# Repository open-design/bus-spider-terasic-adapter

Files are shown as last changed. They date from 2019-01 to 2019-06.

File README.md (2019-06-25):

UEXT adapter board for Terasic FPGA development boards with 40-pin expansion headers.

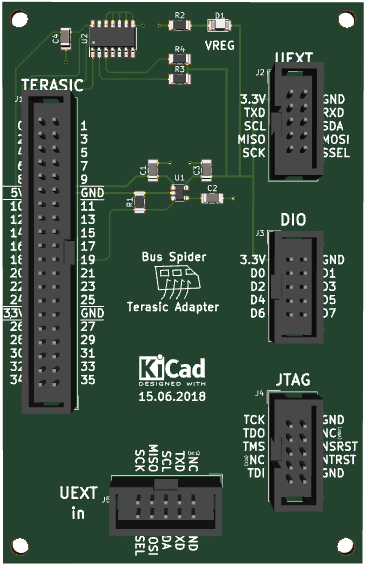
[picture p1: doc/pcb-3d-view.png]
PCB 3D view


## Schematic

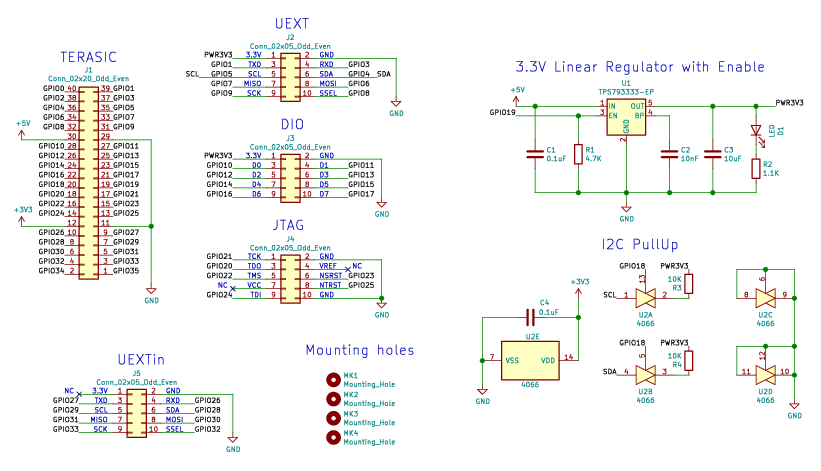
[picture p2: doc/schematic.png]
schematic


## BOM

| name | designation | designator | quantity | supply | datasheets |
| ---  | --- | --- | --- | --- | --- |
| CONNFLY BH-10 | Conn_02x05_Odd_Even | J5,J2,J3,J4 | 4 |  [electronshik.ru](https://www.electronshik.ru/item/CONNFLY/BH-10)<br /> | [pdf](https://static.chipdip.ru/lib/463/DOC002463525.pdf) |
| CONNFLY BH-40 | Conn_02x20_Odd_Even | J1 | 1 |  [electronshik.ru](https://www.electronshik.ru/item/CONNFLY/BH-40)<br /> | [pdf](https://static.chipdip.ru/lib/463/DOC002463525.pdf) |
| Noname LED 1206 | LED | D1 | 1 |  [chipster.ru](https://chipster.ru/catalog/components/optic/leds/smd-led/3029.html)<br /> | no pdf |
| ONS MC14066BDR2G | 4066 | U2 | 1 |  [electronshik.ru](https://www.electronshik.ru/item/ONS/MC14066BDR2G)<br /> [digikey.com](https://www.digikey.com/products/en?keywords=MC14066BDR2G)<br /> [mouser.com](https://mouser.com/Search/Refine.aspx?Keyword=MC14066BDR2G)<br /> [farnell.com](https://uk.farnell.com/search?st=MC14066BDR2G)<br /> | [pdf](https://www.onsemi.com/pub/Collateral/MC14066B-D.PDF) |
| TI TPS79333-EP | TPS79333-EP | U1 | 1 |  [electronshik.ru](https://www.electronshik.ru/item/TI/TPS79333DBVR)<br /> [digikey.com](https://www.digikey.com/products/en?keywords=TPS79333DBVR)<br /> [mouser.com](https://mouser.com/Search/Refine.aspx?Keyword=TPS79333DBVR)<br /> [farnell.com](https://uk.farnell.com/search?st=TPS79333DBVR)<br /> | [pdf](http://www.ti.com/lit/ds/symlink/tps793.pdf) |
| YAGEO CC1206KKX7R8BB106 | 10uF | C3 | 1 |  [electronshik.ru](https://www.electronshik.ru/item/YAG/CC1206KKX7R8BB106)<br /> [digikey.com](https://www.digikey.com/products/en?keywords=CC1206KKX7R8BB106)<br /> [mouser.com](https://mouser.com/Search/Refine.aspx?Keyword=CC1206KKX7R8BB106)<br /> [farnell.com](https://uk.farnell.com/search?st=CC1206KKX7R8BB106)<br /> | [pdf](http://www.yageo.com/exep/pages/download/literatures/ProductSelectionGuide_2018_Final.pdf#page=112) |
| YAGEO CC1206KRX7R9BB103 | 10nF | C2 | 1 |  [electronshik.ru](https://www.electronshik.ru/item/YAG/CC1206KRX7R9BB103)<br /> [digikey.com](https://www.digikey.com/products/en?keywords=CC1206KRX7R9BB103)<br /> [mouser.com](https://mouser.com/Search/Refine.aspx?Keyword=CC1206KRX7R9BB103)<br /> [farnell.com](https://uk.farnell.com/search?st=CC1206KRX7R9BB103)<br /> | [pdf](http://www.yageo.com/exep/pages/download/literatures/ProductSelectionGuide_2018_Final.pdf#page=112) |
| YAGEO CC1206KRX7R9BB104 | 0.1uF | C1,C4 | 2 |  [electronshik.ru](https://www.electronshik.ru/item/YAG/CC1206KRX7R9BB104)<br /> [digikey.com](https://www.digikey.com/products/en?keywords=CC1206KRX7R9BB104)<br /> [mouser.com](https://mouser.com/Search/Refine.aspx?Keyword=CC1206KRX7R9BB104)<br /> [farnell.com](https://uk.farnell.com/search?st=CC1206KRX7R9BB104)<br /> | [pdf](http://www.yageo.com/exep/pages/download/literatures/ProductSelectionGuide_2018_Final.pdf#page=112) |
| YAGEO RC1206FR-0710KL | 10K | R3,R4 | 2 |  [electronshik.ru](https://www.electronshik.ru/item/YAG/RC1206FR-0710KL)<br /> [digikey.com](https://www.digikey.com/products/en?keywords=RC1206FR-0710KL)<br /> [mouser.com](https://mouser.com/Search/Refine.aspx?Keyword=RC1206FR-0710KL)<br /> [farnell.com](https://uk.farnell.com/search?st=RC1206FR-0710KL)<br /> | [pdf](http://www.yageo.com/exep/pages/download/literatures/ProductSelectionGuide_2018_Final.pdf#page=8) |
| YAGEO RC1206FR-071K1L | 1.1K | R2 | 1 |  [electronshik.ru](https://www.electronshik.ru/item/YAG/RC1206FR-071K1L)<br /> [digikey.com](https://www.digikey.com/products/en?keywords=RC1206FR-071K1L)<br /> [mouser.com](https://mouser.com/Search/Refine.aspx?Keyword=RC1206FR-071K1L)<br /> [farnell.com](https://uk.farnell.com/search?st=RC1206FR-071K1L)<br /> | [pdf](http://www.yageo.com/exep/pages/download/literatures/ProductSelectionGuide_2018_Final.pdf#page=8) |
| YAGEO RC1206FR-074K7L | 4.7K | R1 | 1 |  [electronshik.ru](https://www.electronshik.ru/item/YAG/RC1206FR-074K7L)<br /> [digikey.com](https://www.digikey.com/products/en?keywords=RC1206FR-074K7L)<br /> [mouser.com](https://mouser.com/Search/Refine.aspx?Keyword=RC1206FR-074K7L)<br /> [farnell.com](https://uk.farnell.com/search?st=RC1206FR-074K7L)<br /> | [pdf](http://www.yageo.com/exep/pages/download/literatures/ProductSelectionGuide_2018_Final.pdf#page=8) |

## Links

* [InnovateFPGA 2018 | EM099 | Bus Spider](http://www.innovatefpga.com/cgi-bin/innovate/teams2018.pl?Id=EM099)
* [Bus Spider: flexible open source hacker multi-tool](https://github.com/miet-riscv-workgroup/de10-nano-bus-spider)
* [Olimex UEXT board to board connector](https://www.olimex.com/Products/Modules/UEXT/)
* [Dangerous Prototypes: Bus Pirate v3.6](http://dangerousprototypes.com/docs/Bus_Pirate_v3.6)

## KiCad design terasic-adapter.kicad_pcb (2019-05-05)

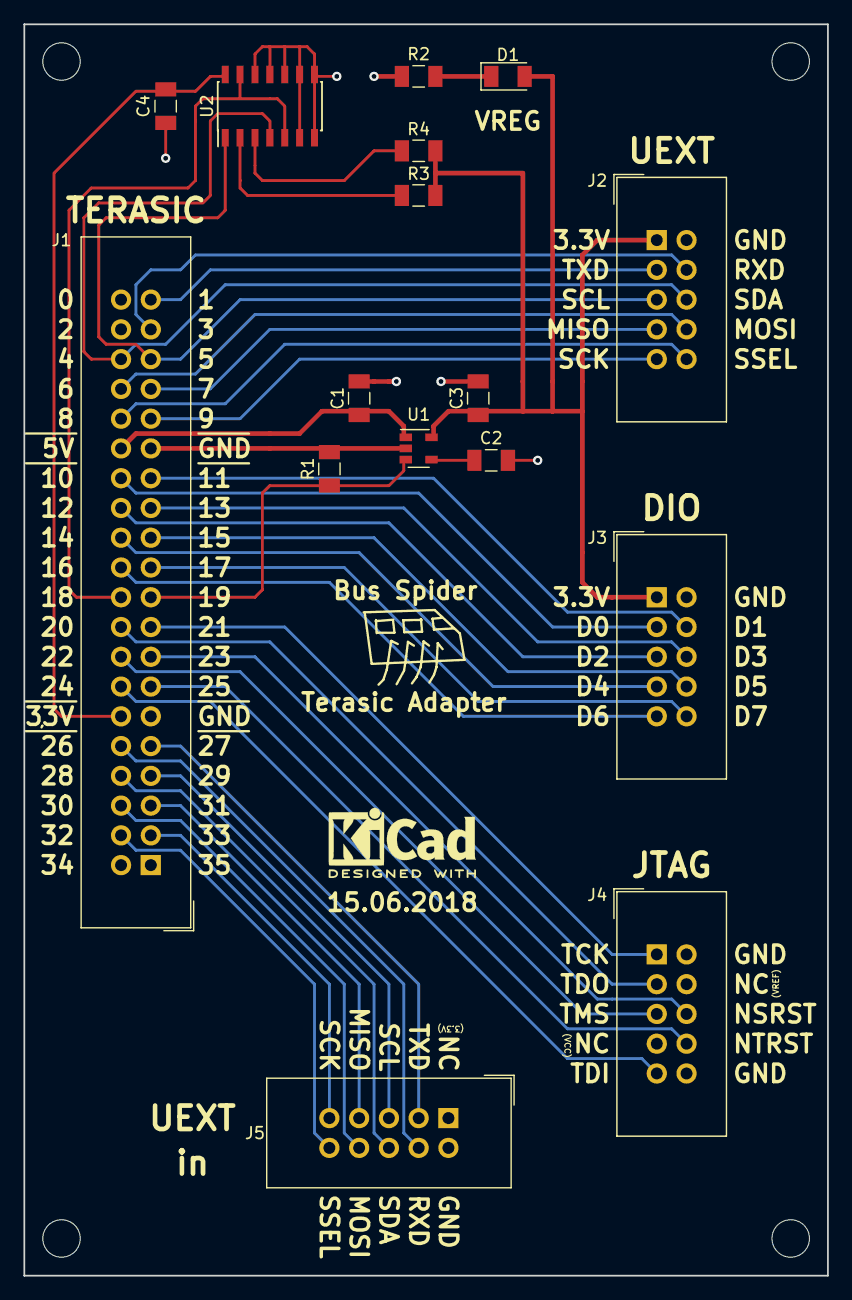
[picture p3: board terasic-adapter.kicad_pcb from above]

Board: 2 copper layers, 68.6 x 106.8 mm, 20 parts (0 on the bottom side), 40 nets.

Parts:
C1, C4: 0.1uF; C_1206_3216Metric
C2: 10nF; C_1206_3216Metric
C3: 10uF; C_1206_3216Metric
D1: LED; LED_1206_3216Metric
J1: Conn_02x20_Odd_Even; IDC-Header_2x20_P2.54mm_Vertical
J2, J3, J4, J5: Conn_02x05_Odd_Even; IDC-Header_2x05_P2.54mm_Vertical
MK1, MK2, MK3, MK4: Mounting_Hole; MountingHole_3.2mm_M3
R1: 4.7K; R_1206_3216Metric
R2: 1.1K; R_1206_3216Metric
R3, R4: 10K; R_1206_3216Metric
U1: TPS79333-EP; SOT-23-5
U2: 4066; SOIC-14_3.9x8.7mm_P1.27mm

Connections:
+3V3: C4.2, J1.12, U2.14
+5V: C1.1, J1.30, U1.1
/GPIO1: J1.39, J2.3
/GPIO3: J1.37, J2.4
/GPIO4: J1.36, J2.6, U2.4
/GPIO5: J1.35, J2.5, U2.1
/GPIO6: J1.34, J2.8
/GPIO7: J1.33, J2.7
/GPIO8: J1.32, J2.10
/GPIO9: J1.31, J2.9
/GPIO10: J1.28, J3.3
/GPIO11: J1.27, J3.4
/GPIO12: J1.26, J3.5
/GPIO13: J1.25, J3.6
/GPIO14: J1.24, J3.7
/GPIO15: J1.23, J3.8
/GPIO16: J1.22, J3.9
/GPIO17: J1.21, J3.10
/GPIO18: J1.20, U2.5, U2.13
/GPIO19: J1.19, R1.1, U1.3
/GPIO20: J1.18, J4.3
/GPIO21: J1.17, J4.1
/GPIO22: J1.16, J4.5
/GPIO23: J1.15, J4.6
/GPIO24: J1.14, J4.9
/GPIO25: J1.13, J4.8
/GPIO26: J1.10, J5.4
/GPIO27: J1.9, J5.3
/GPIO28: J1.8, J5.6
/GPIO29: J1.7, J5.5
/GPIO30: J1.6, J5.8
/GPIO31: J1.5, J5.7
/GPIO32: J1.4, J5.10
/GPIO33: J1.3, J5.9
/PWR3V3: C3.1, D1.2, J2.1, J3.1, R3.2, R4.2, U1.5
GND: C1.2, C2.2, C3.2, C4.1, J1.11, J1.29, J2.2, J3.2, J4.2, J4.10, J5.2, R1.2, R2.2, U1.2, U2.6, U2.7, U2.8, U2.9, U2.10, U2.11, U2.12
unnamed: C2.1, U1.4
unnamed: D1.1, R2.1
unnamed: R3.1, U2.2
unnamed: R4.1, U2.3

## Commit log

2019-01-05 Import kicad scripts by Scott Bezek
    Original Scott Bezek's scripts can be found here:
    https://github.com/scottbez1/splitflap/tree/master/electronics/
    Usage:
    ./scripts/generate_gerber.py terasic-adapter.kicad_pcb
    ./scripts/generate_pdf.py terasic-adapter.kicad_pcb
    ./scripts/generate_svg.py terasic-adapter.kicad_pcb
    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
2019-01-05 terasic-adapter.sch: adapt mounting holes for Debian kicad-symbols 5.0.2-1
    See this kicad-symbols commit for details:
    | commit d4764750700ab725bbe5e3e0cd33c768fa56a677
    | Author: Antonio Vázquez <antoniovazquezblanco@gmail.com>
    | Date: Wed May 23 12:43:00 2018 +0200
    |
    | Mechanical: Rename mounting holes to be consistent and update FPFilters
    [terasic-adapter.sch]
2019-01-07 add parse_csv_bom.py script
    # In PCB Layout Editor
    # File -> Fabrication Outputs -> BOM File -> Save terasic-adapter.csv
    BOARD_NAME=terasic-adapter
    BOM=build/${BOARD_NAME}-bom
    mkdir -p build
    scripts/parse_csv_bom.py ${BOARD_NAME}.csv > ${BOM}.md
    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
2019-01-07 README.md: add BOM generated by parse_csv_bom.py
2019-01-07 add pcb 3D view and schematic pictures
2019-05-05 fix part spelling for TPS79333-EP
    Fixed in upstream https://github.com/kicad/kicad-symbols
    by commit 5da4de5bcafbec757f83fc1941268a7594b1ae7c
    (fix part spelling for TPS79333-EP)
    [terasic-adapter.kicad_pcb, terasic-adapter.sch]
